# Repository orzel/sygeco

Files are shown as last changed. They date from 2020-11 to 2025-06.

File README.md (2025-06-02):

Small console based on attiny85, compatible with tinyjoypad.

The official homepage is https://projects.freehackers.org/sygeco1/
and the mercurial repository is at https://freehackers.org/electronics/sygeco1/

It is developed by [Thomas Capricelli](https://freehackers.org/thomas/).

The `hardware/` directory contains kicad files for the schematics and pcb, as well as some support files for parts and 3d rendering.
The `launcher/` directory provides a PyQt script to easily select and program ("upload") any game. It's easily customizable, if you want to add/change games or configure the `avrdude` programmer used.

No games is included in the repository, though. The project page has a zip file with the launcher and most available games, pre-configured.

I can be contacted [on this page](https://www.freehackers.org/thomas/feedback/).

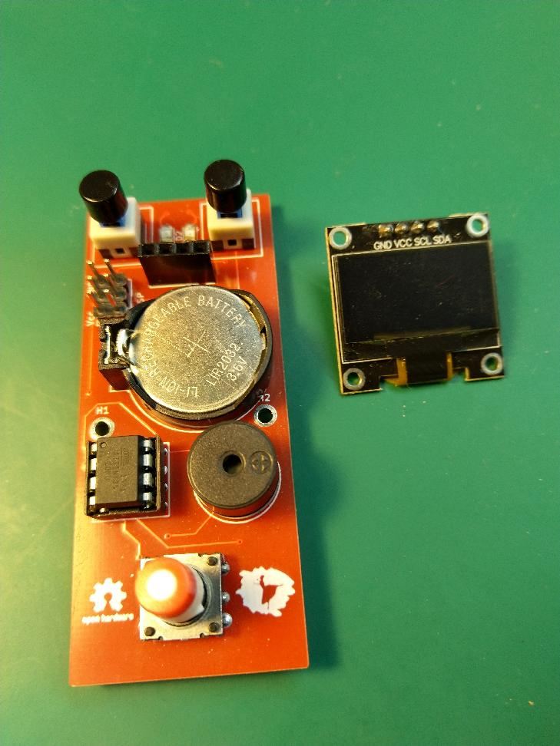
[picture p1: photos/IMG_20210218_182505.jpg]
Main board with screen removed

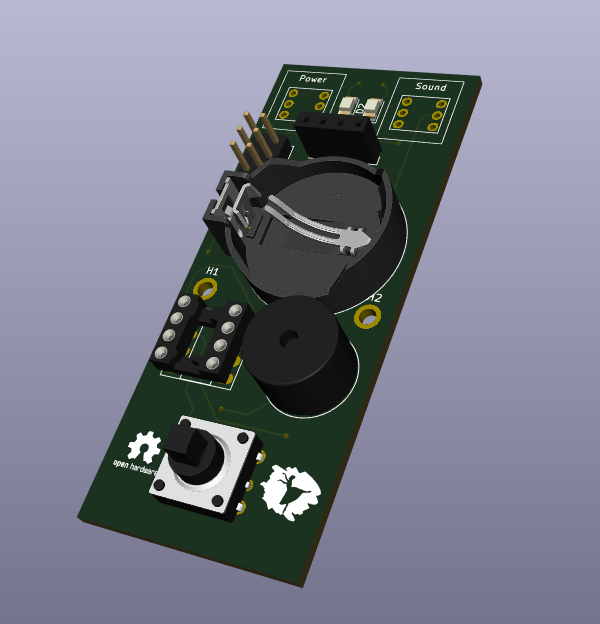
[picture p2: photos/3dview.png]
3D view


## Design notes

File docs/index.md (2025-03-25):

# Sygeco 1

There are several *implementations* of the tinyjoypad mini-console, but none **was** actually open, so I couldn't adapt/play with it.
This is my take on it. I also wrote a child-friendly interface to allow for changing the game (aka *flash new firmware*).

This is [open hardware](https://en.wikipedia.org/wiki/Open-source_hardware),
the PCB is designed with [KiCad](https://en.wikipedia.org/wiki/KiCad), and source files can be found on the
([mercurial](https://en.wikipedia.org/wiki/Mercurial)) repository at [https://freehackers.org/electronics/sygeco1](https://freehackers.org/electronics/sygeco1).

It is developed by [Thomas Capricelli](https://freehackers.org/thomas/).

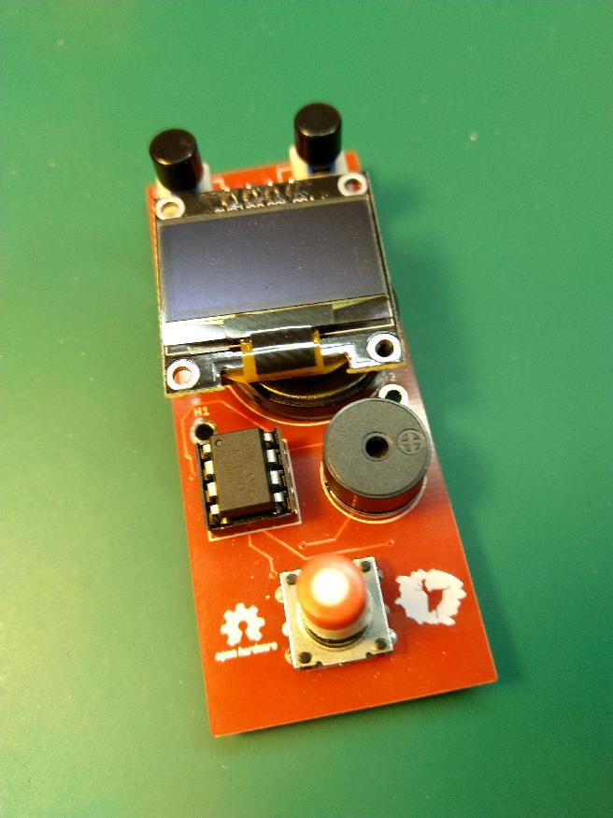
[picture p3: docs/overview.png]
overview


## Introduction

The tinyjoypad is a fun exemple of how minimalist a *game console* can be. The schematic is so simple, that a breadboard photo is enough, and the software is open (arduino). That sounded great !

I had some (dip8) attiny85 around, as well as the very famous small oled display, so it was very quick to get the breadboard implementation working, and my children urging me to let them play on it. But, well, breadboard is not good for actual playing.

There *were* some PCB variations on the web, and even on [hackaday](https://hackaday.io/search?term=tinyjoypad). You could maybe get the gerbers, but not the schematics. Not as open as I would have liked. (I come from the software opensource community). 

I needed to learn how to make a PCB anyway, so here's my version. It has the following features:

* CR2032 holder for power supply. The console can support both usual cr2032 battery (~3V) and LiPo version (3.5~4.2 V). We use the LiPo battery and it's very useful. The console doesn't have any LiPo charging support though, you need an external charger.
* sound switch ( huge [waf](https://en.wikipedia.org/wiki/Wife_acceptance_factor) !)
* sound slightly lighter by lowering the voltage at audio speaker (again, huge waf !)
* 5-way joystick instead of tactile switches.
* standard ISP connector for changing games (flashing the MCU)

I also wrote a small application to easily change the game on the console.

I did that before I was aware of [this great project](https://github.com/Yevgeniy-Olexandrenko/tiny-handheld), which appeared at the same time. The end-result is pretty similar. The 'tiny handheld' also has audio switch and ISP, and most importantly, the schematic is available (based on EasyEDA). It features an eeprom, not sure why.

It should accept any 'game' made for the tinyjoypad, including those by the original author, and others. Yevgeniy Olexandrenko did a great job [gathering the binaries on his page](https://github.com/Yevgeniy-Olexandrenko/tiny-handheld/tree/master/software/games).

The project was developed using KiCad, all files are on the repository (schematics, PCB, and final gerbers for printing).

## Launcher

On the repository, under the `launcher/` directory, you can find a quick PyQt-based interface that displays a grid of games, and will program the one you click on. You need to have `PyQt` installed (of course) and the ubiquitous `avrdude` programmer on the path. It's tested on Linux, but should work on any platform with `PyQt` and `avrdude` available. You can easily tweak the script to change the games list: you need a binary and an preview image for each game, all in the script directory. You may want to change the few messages displayed to 'users'.

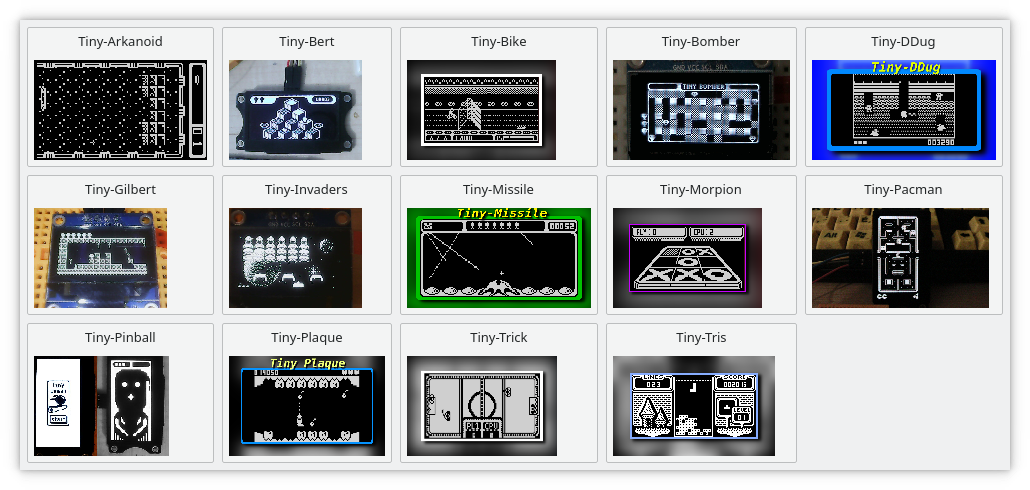
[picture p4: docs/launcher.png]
launcher


## Programming

I use an `USBasp` programmer, but you can use anything you want. The connector on the board is extremely standard, and `avrdude` very probably support your programmer. Just configure the proper programmer at the top of the script.

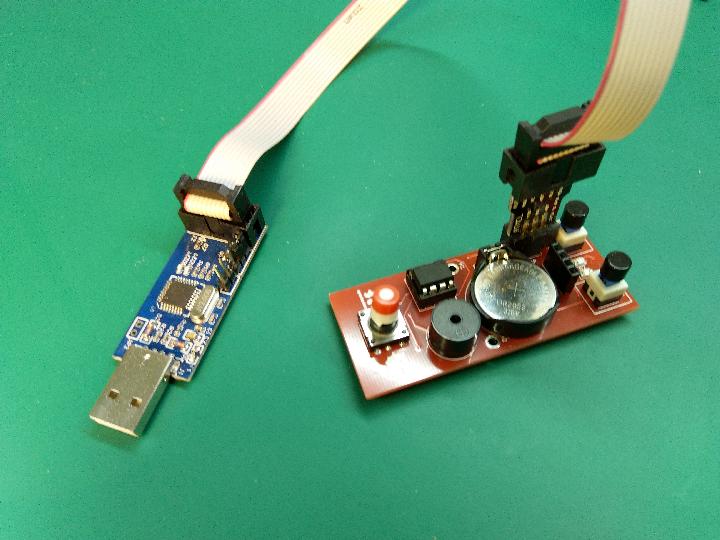
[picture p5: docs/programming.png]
programming


## Charging

For charging the LiPo button batteries, I use those very very cheap TP4056-based chargers you can find on chinese sites, with a battery holder soldered directly. The charging current is kinda configurable on those modules, and the default is suitable for normal batteries. Those LIR2306 are much smaller, so i've changed the configuration resistor from 1k to 10k (see the datasheet). Problem is, the resistor is some very very very small smd, and I only got HUGE 1206. I ended soldering it directly to one pin of the 4056. Once done,  it works perfectly.

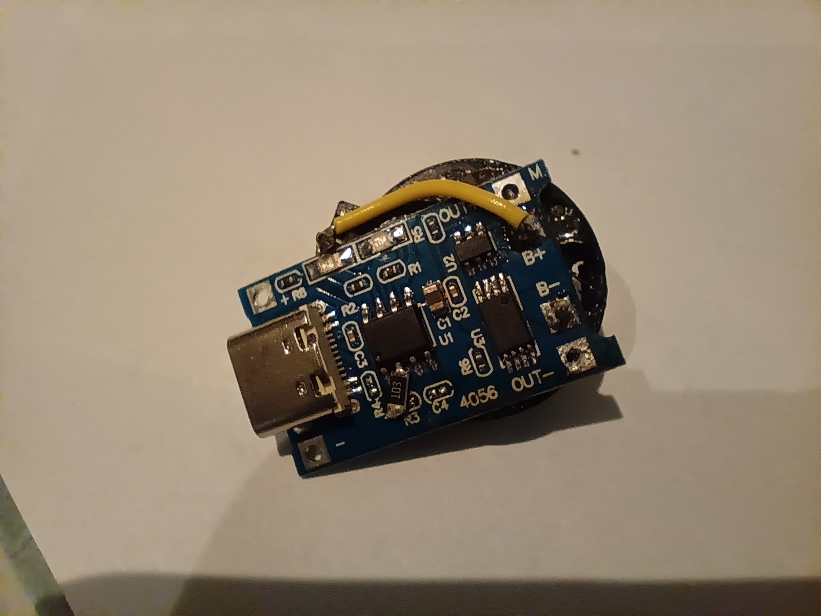
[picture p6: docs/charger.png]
charger


## Compilation

Compiling even the original exemples is tricky. Here are the information I would have liked to find somewhere.

The 'games' are actually arduino sketches. But arduino 'as is' doesn't support bare attiny85. You need to instal a package
(a [BSP](https://en.wikipedia.org/wiki/Board_support_package) actually).
The right one is [https://github.com/damellis/attiny](https://github.com/damellis/attiny).

Summary: you need to add an URL in `File/Preferences/AdditionalBoardsManager`, then select the righ package in menu `Tools/Board/Boards` Manager.
Then configure in the new menu appearing: first the "board" ("Attiny/25/45/85"), then the processor (85 obviously), and fnially the frequency ("Internal 16MHz").

That was the easy part. The tricky part is about the OLED driver. It's called 'ssd1306xled', but there are actually a lot of variations with this name. And most importantly, you'll find a library with such a name in the standard arduino packages manager. But this is not the right one. Using this standard one will create binaries very slightly bigger than the maximum size. Which is small, it's called 'tiny' for a reason.

The right one to use is [https://github.com/Defragster/ssd1306xled](https://github.com/Defragster/ssd1306xled), and
you can copy/clone this under your arduino libraries directory, bypassing the interface installer. On linux that means `~/.Arduino/libraries/`.

## Weird values for resistors

To detect keys, the tinyjoypad uses resistor dividers and the internal [ADC](https://en.wikipedia.org/wiki/Analog-to-digital_converter) of the MCU. One on each direction (left/right, and up/down).

If you look at the schematic, you'll notice that the resistors values are weird. We would typically expect something like this to allow for maximum tolerance:

* voltage < vpp/3 : one direction
* voltage > 2 \* vpp/3 : other direction
* otherwise no button is detected.

The reason for those strange values, which imho deserves an explanation, is that the left/right direction is wired to the PIN1 of the chip. The attiny85 is very limited on i/o, and we have to deal with the fact that pin1 is **also** the reset pin. If the voltage is too low (say, less than half vpp), the chip will reset/reboot. The good news is that if we stay on the upper half, we can still use the internal ADC, and that's what the original design takes advantage of. Hence those weird values..

## Challenges

Designing the schematic and PCB was ok. We enjoy having those small joystick-like inputs, usually called "5-way switches". The main problem was to find proper components. Most of them were obviously easy (resistors.. even the oled). But at this time I have yet to find a proper "cap" for the joystick. It uses a very common/typical square 3.2mm axle, for which you can find cheap cap on the market. But they are too long/deep. We still rely on cutting them with a knife, which is ... unfortunate.

## Bill of material

There's a `bom.fods` file on the repository, that you can open with `libreoffice`. The overall cost is about 6€. The heaviest parts, and also those that most hobbyists probably already have are the OLED display, the attiny85 and the battery. Without those parts, the cost is around 2€, including the PCB.

Things to be aware of:

* joystick / 5-way switches: I've used no-name chinese components, but I guess they are based on a standard one (probably the SKQUCAA010 from Alps or Alpine brand). All those found on internet have the same characterics, most importantly the footprint, so there's not real risk here. Just be sure to use the through-hole version, there exists a SMD one.
* OLED display: you can find them everywhere, but be careful that the wiring might be different. The PCB uses the (I think) most common one with pins in this order: `GND, VDD, SCK, SDA`. You can find them with different led colors, and my children enjoy being able to change the display color as they wish.

3dview

## Random notes

There are holes on the PCB to fix the oled display using 11/12mm standoffs + screws. Unfortunately, the OLED modules you find are all different on this regard. Even the few I have are not compatible, and yours will probably be different. Anyway, you need to remove the display for changing the battery or the game. The idea was to 'harden' it slightly so that it could be brought to school.

## Replicating

It's easy for you to replicate this project. The easiest way is to use the provided gerbers and use one of the common "PCB printing" services. The parts are all standard and easy to find.

I've used SMD components, but only the biggest ones (1206). If you know how to solder through-hole components, it really is not more difficult. It was the first time for me, and it went very well.

The PCB allows for both variant of the MCU: through-hole, and SMD. I choose the through-hole version of the joystick for machanical reasons.

I do not intend to provide kits on tindie or whatever. I have a few spare PCBs though, [contact me](https://freehackers.org/thomas/feedback/)
if interested, especially if you happen to live near Paris/France.

A very useful tool while soldering is the [interactive bom](ibom.html).

## Downloads

The reference is the repository, but for your convenience, here are some 'final products' downloads (revision 1.2).

* [sygeco-1.2.launcher.zip](https://projects.freehackers.org/downloads/sygeco-1.2.launcher.zip) : launcher + all games and images I could find.
* [sygeco-1.2.gerbers.zip](https://projects.freehackers.org/downloads/sygeco-1.2.gerbers.zip) : Gerber files, all files required for "PCB printing".

## Gallery

Some more photos and images:

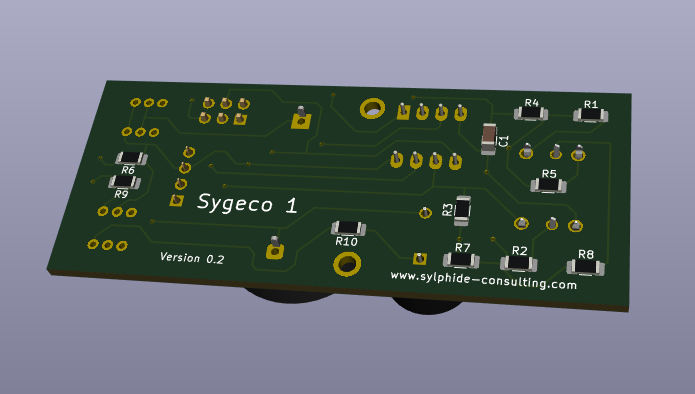
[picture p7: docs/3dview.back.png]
3dview.back


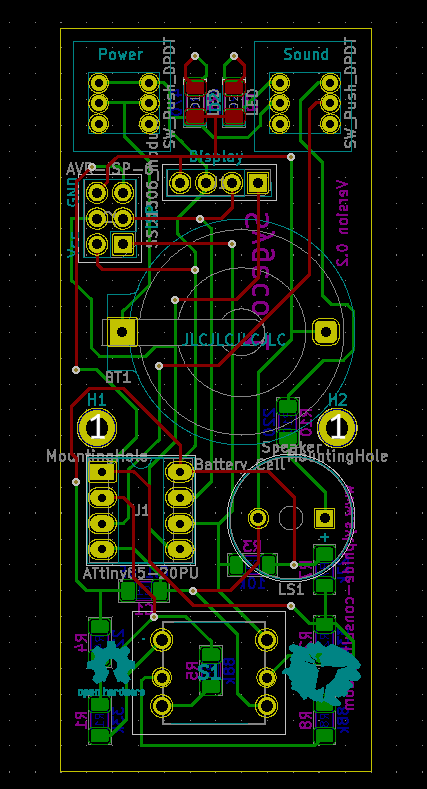
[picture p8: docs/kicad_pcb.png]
KiCad pcb


overview 2

A funny, beautiful, interactive 3D view of [the populated PCB](kicad-pcb-3dview.html)

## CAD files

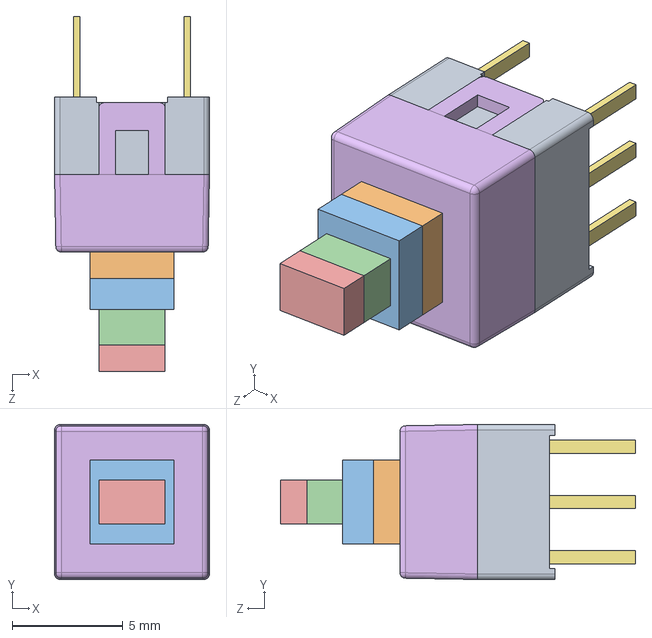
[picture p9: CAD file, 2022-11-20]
hardware/3dmodels/LatchSwitch_7x7.STEP
7.00 x 7.00 x 16.1 mm

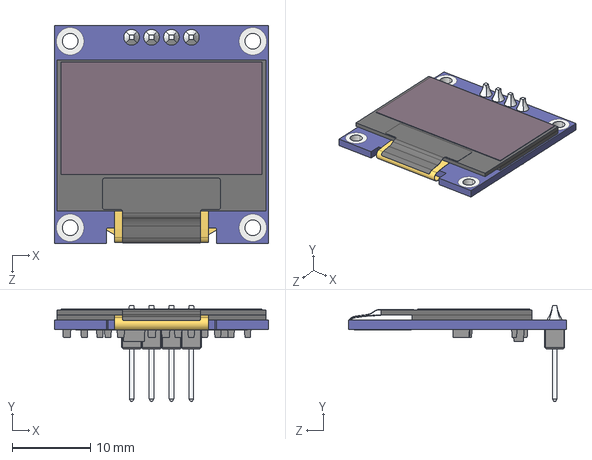
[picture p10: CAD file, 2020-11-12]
hardware/3dmodels/OLED TFT 0.96 inch 64x128 monochrome.STEP
27.3 x 12.3 x 27.8 mm

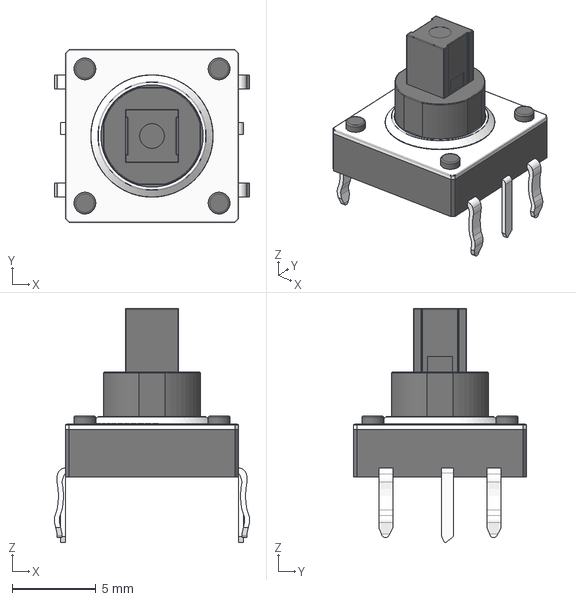
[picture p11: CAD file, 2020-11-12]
hardware/3dmodels/5-WayTactileButton10mmTHT.stp
11.6 x 10.3 x 14.0 mm

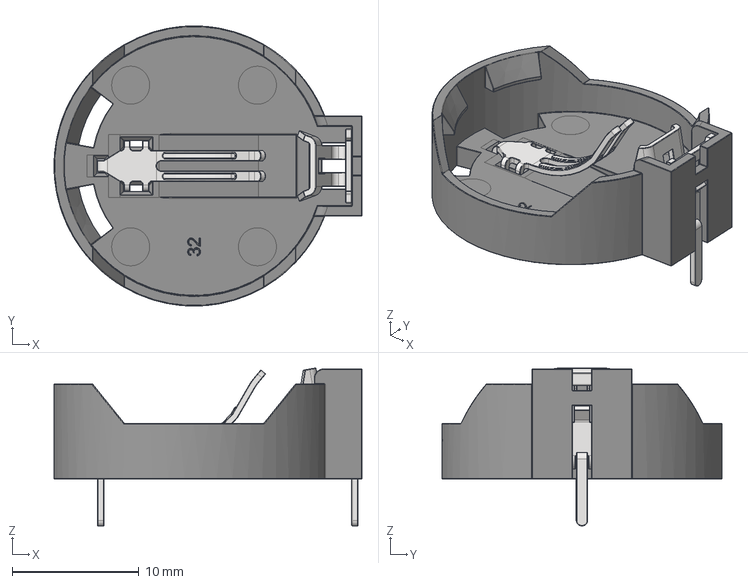
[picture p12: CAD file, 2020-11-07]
hardware/3dmodels/ChineseCR2032Holder.stp
24.3 x 22.1 x 12.5 mm

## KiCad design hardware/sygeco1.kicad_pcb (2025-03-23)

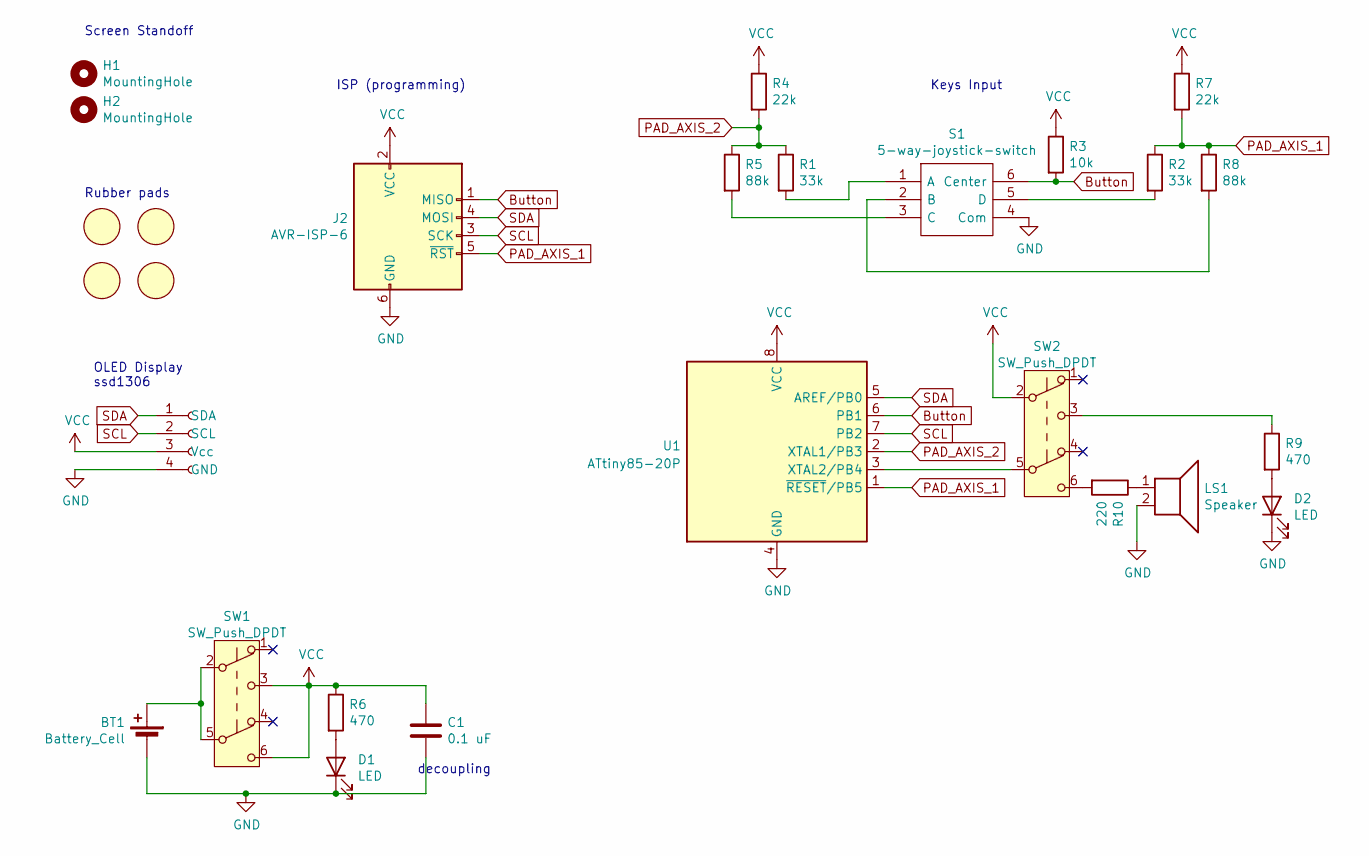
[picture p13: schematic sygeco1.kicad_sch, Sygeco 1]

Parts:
BT1: Battery_Cell; BatteryHolder_China_1x20mm
C1: 0.1 uF; C_1206_3216Metric_Pad1.33x1.80mm_HandSolder
D1, D2: LED; LED_1206_3216Metric
H1, H2: MountingHole; MountingHole_2.2mm_M2_ISO7380_Pad
J1: SSD1306_module; PinSocket_1x04_P2.54mm_Vertical
J2: AVR-ISP-6; PinHeader_2x03_P2.54mm_Vertical
LS1: Speaker; MagneticBuzzer_ProSignal_ABT-410-RC
R1, R2: 33k; R_1206_3216Metric_Pad1.30x1.75mm_HandSolder
R3: 10k; R_1206_3216Metric_Pad1.30x1.75mm_HandSolder
R4, R7: 22k; R_1206_3216Metric_Pad1.30x1.75mm_HandSolder
R5, R8: 88k; R_1206_3216Metric_Pad1.30x1.75mm_HandSolder
R6, R9: 470; R_1206_3216Metric_Pad1.30x1.75mm_HandSolder
R10: 220; R_1206_3216Metric_Pad1.30x1.75mm_HandSolder
RP1, RP2, RP3, RP4: silicone_rubber_pad
S1: 5-way-joystick-switch; SKQUCAA010; Manufacturer_Part_Number SKQUCAA010; Mouser Part Number 688-SKQUCA
SW1, SW2: SW_Push_DPDT; DPDT_Switch_with_lock
U1: ATtiny85-20P; DIP-8_W7.62mm

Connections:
Button: J2.1 (MISO), R3.2, S1.6 (Center), U1.6 (PB1)
GND: BT1.2 (-), C1.2, D1.1 (K), D2.1 (K), J1.4 (GND), J2.6 (GND), LS1.2, S1.4 (Com), U1.4 (GND)
unnamed: BT1.1 (+), SW1.2 (B), SW1.5 (B)
unnamed: D1.2 (A), R6.2
unnamed: D2.2 (A), R9.2
unnamed: LS1.1, R10.1
unnamed: R1.2, S1.1 (A)
unnamed: R2.2, S1.5 (D)
unnamed: R5.2, S1.3 (C)
unnamed: R8.2, S1.2 (B)
unnamed: R9.1, SW2.3 (C)
unnamed: R10.2, SW2.6 (C)
unnamed: SW2.5 (B), U1.3 (XTAL2/PB4)
PAD_AXIS_1: J2.5 (~RST), R2.1, R7.2, R8.1, U1.1 (~RESET/PB5)
PAD_AXIS_2: R1.1, R4.2, R5.1, U1.2 (XTAL1/PB3)
SCL: J1.2 (SCL), J2.3 (SCK), U1.7 (PB2)
SDA: J1.1 (SDA), J2.4 (MOSI), U1.5 (AREF/PB0)
VCC: C1.1, J1.3 (Vcc), J2.2 (VCC), R3.1, R4.1, R6.1, R7.1, SW1.3 (C), SW1.6 (C), SW2.2 (B), U1.8 (VCC)

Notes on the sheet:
Screen Standoff
decoupling
Rubber pads
OLED Display ssd1306
Keys Input
ISP (programming)

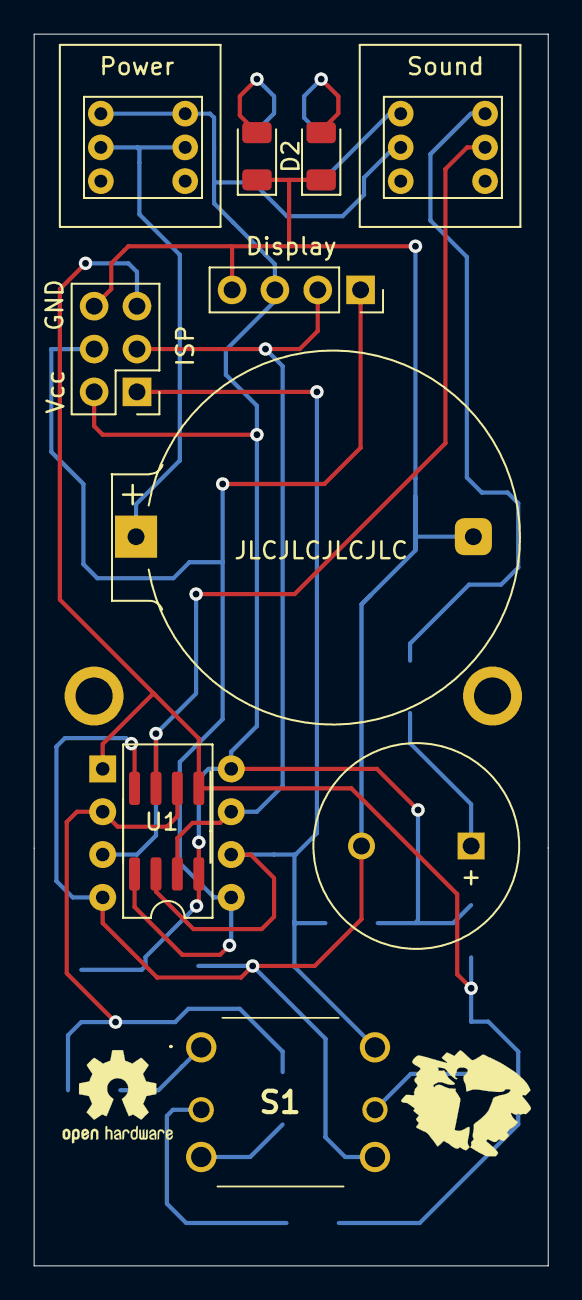
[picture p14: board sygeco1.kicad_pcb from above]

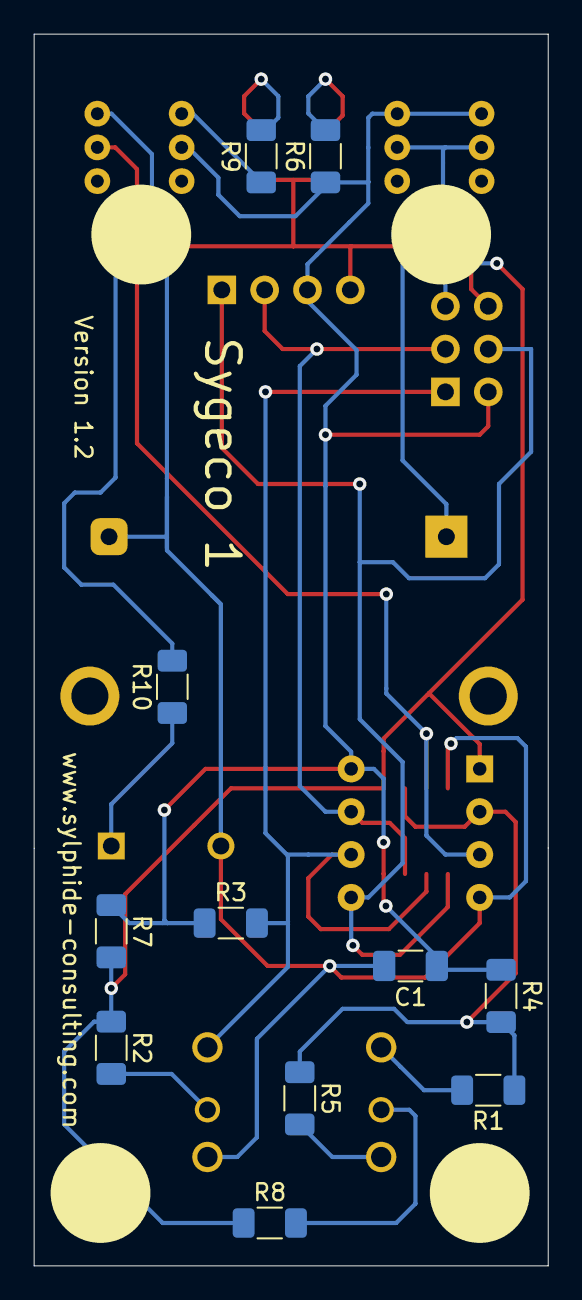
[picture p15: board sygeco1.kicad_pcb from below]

Board: 2 copper layers, 30.5 x 73.0 mm, 27 parts (15 on the bottom side), 18 nets.

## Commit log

2020-11-04 blank new kicad project
    [sygeco1.kicad_pcb, sygeco1.sch]
2020-11-06 Done schematic + pcb routing
    [sygeco1.kicad_pcb, sygeco1.sch]
2020-11-06 hard to understand the purpose of all kicad file types..
2020-11-06 add some text/logo
    [sygeco1.kicad_pcb, sygeco1.sch]
2020-11-07 keep on 'improving'. Changed beeper and cell battery holder, according to what i can get my hand on.
    [ChineseCR2032Holder.stp, sygeco1.kicad_pcb, sygeco1.sch]
2020-11-07 add an ISP header, a power led, and redo completely the routing: * the board is bigger, but hopefully more 'practical' to use * using two layers of copper. it's the same price, why bother ?
    [sygeco1.kicad_pcb, sygeco1.sch]
2020-11-07 commit gerber/drill files ("output")
    [sygeco1-B_CrtYd.gbr, sygeco1-B_Cu.gbr, sygeco1-B_Mask.gbr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]
2020-11-07 add decoupling capacitor, use same value for keypad resistors, it's simpler
    [sygeco1.kicad_pcb, sygeco1.sch]
2020-11-08 oops, the oled connector position was inversed, fixed that
    [sygeco1.kicad_pcb]
2020-11-12 cleaning / small improvements
    [5-WayTactileButton10mmTHT.stp, OLED TFT 0.96 inch 64x128 monochrome.STEP, sygeco1.kicad_pcb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]
2020-11-12 update gerbers, we use both Cu planes now
    [sygeco1-B_CrtYd.gbr, sygeco1-B_Cu.gbr, sygeco1-B_Mask.gbr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]
2020-11-12 start working on the BOM
2020-11-12 pcb makers want a zip
2020-11-18 copy all games from https://www.tinyjoypad.com/tinyjoypad_attiny85 * remove schematics * remove screenshots * remove hex * moved COPYING.txt one level up. md5s for all COPYING.txt were exactly the sa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
2020-11-18 rename *.ino to please arduino IDE
2020-12-03 few fixes * sch: fix typo (axe -> axis) * reduce battery holder hole size now that i have the actual device to check * some routing cleaning * contrary to my expectation, the isp header works as is, 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
    [sygeco1.kicad_pcb, sygeco1.sch]
2020-12-13 add mounting holes for the screen
    [sygeco1.kicad_pcb, sygeco1.sch]
2020-12-13 Restore original (tinyjoypad) input schematics, with dual resistors and reset pin >= vcc/2
    [sygeco1.kicad_pcb, sygeco1.sch]
2020-12-13 Add a led to provide feedback about whether the sound is enable or not.
    [sygeco1.kicad_pcb, sygeco1.sch]
2020-12-13 Add a resistor to lower the level of buzzer (especially when using li-ion battery, with higher voltage) + fixes leds resistors.
    [sygeco1.kicad_pcb, sygeco1.sch]
2020-12-14 Added tag pcb-production-0.1 for changeset 0c22d51a9606
2020-12-14 final touch + generates files for pcb production
    [sygeco1-B_CrtYd.gbr, sygeco1-B_Cu.gbr, sygeco1-B_Mask.gbr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]
2020-12-14 not sure what kicad changed here..
    [sygeco1.kicad_pcb]
2020-12-14 update bom
2021-01-08 Make battery holders via holes slightly bigger. They fit as is, but it was tight.
    [sygeco1.kicad_pcb]
2021-01-08 Added tag pcb-production-0.2 for changeset a1f5023423d9
2021-02-18 update all generated files before release
    [sygeco1-B_CrtYd.gbr, sygeco1-B_Cu.gbr, sygeco1-B_Mask.gbr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]
2021-02-18 update revision (1.0)
    [sygeco1-B_CrtYd.gbr, sygeco1-B_Cu.gbr, sygeco1-B_Mask.gbr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]
2021-02-23 Implement translations (or i18n if you prefer). Switch to English as main language, and French is now the only translation. Feel free to send me any other if you wish.
2021-12-12 migrated files to kicad 6.0 (-rc1)
    [sygeco1.kicad_pcb, sygeco1.kicad_sch, sygeco1.sch]
2022-11-20 random cleaning, mostly kicad updating its stuff
    [sygeco1.kicad_pcb, sygeco1.kicad_sch]
2022-11-20 add 3d model for DPDT switches
    [LatchSwitch_7x7.STEP, sygeco1.kicad_pcb]
2022-11-20 use https://github.com/github/gitignore/blob/main/KiCad.gitignore for kicad files
2022-11-20 Create new symbol+footprint for basic rubber pads.
2022-11-24 Add some (silicone) pads. pcb: cleaning all errors/warnings
    [sygeco1.kicad_pcb, sygeco1.kicad_sch]
2022-11-24 Better align pads
    [sygeco1.kicad_pcb]
2022-11-24 Fix attiny85 symbol + all errors/warnings. Seems like my symbol was obsolate..(?)
    [sygeco1.kicad_pcb, sygeco1.kicad_sch]
2022-11-25 slight offset on batteryholder 3d model
    [sygeco1.kicad_pcb]
2022-11-25 Add dual footprints for the MCU. This way you can put either a dip8 or a sop8. Quite useful in those times of parts shortage.
    [sygeco1.kicad_pcb, sygeco1.kicad_sch]
2023-02-21 output files for 1.1
    [sygeco1-B_Courtyard.gbr, sygeco1-B_CrtYd.gbr, sygeco1-B_Cu.gbr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]
2024-06-16 no more with recent kicad
2024-06-16 switching to kicad 8
    [sygeco1.kicad_pcb, sygeco1.kicad_sch]
2025-03-22 update symbols + revision
    [sygeco1.kicad_sch]
2025-03-22 dunno.. probably changes induced by a more recent version of kicad
2025-03-22 was referencing the old 'sygeco' local symbol library, fixed that to sygeco1
    [sygeco1.kicad_pcb, sygeco1.kicad_sch]
2025-03-22 kicad doing its stuff.. ?
    [sygeco1.kicad_pcb]
2025-03-22 updated from schematics
    [sygeco1.kicad_pcb]
2025-03-22 update schematic revision as well
    [sygeco1.kicad_pcb]
2025-03-22 Add generated page, by the superb 'interactive html bom' plugin.
2025-03-22 the real name is 'sygeco 1'
    [sygeco1.kicad_pcb]
2025-03-22 add an interactive page witht the pcb in 3d requires proper js files on server.
2025-03-23 wikipedia seems to say KiCad is the proper spelling
2025-03-23 update version as displayed on pcb yeah, kicad has something about 'variables' i could surely use here
    [sygeco1.kicad_pcb]
2025-03-23 We now provide a downloadble zip, no need to keep those generated files in source control anymore.
    [sygeco1-B_Courtyard.gbr, sygeco1-B_Cu.gbr, sygeco1-B_Mask.gbr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]
2025-03-24 It behaves weirdly when rotating, which was not the case in my previous testing..
